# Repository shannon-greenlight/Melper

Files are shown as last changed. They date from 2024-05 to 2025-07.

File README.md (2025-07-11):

# The Melper
The Melper converts a Moog case into a powered Eurorack case.

It requires +12V as an input and generates -12V and +5V.
These 3 voltage rails supply 6 Eurorack power connectors.
Three LEDs monitor the supply rails.
It is targeted to Moog cases, but can be used in any case that has +12V.
The 12 volt wall wart that Moog supplies works well. 

This repo contains the schematic and layout files needed to create the Melper.
These files are for KiCAD Version: 8.0.8

The repo contains the BOM files that are used to buy the components.
These are found in the _BOM_ folder.
The BOM files for DigiKey and JLCPCB are provided in .csv format.
Other suppliers typically will accept these files with minor modifications.

The repo also contains the files needed for fabrication. These are found in the _fab_ folder.
These include the gerber files, which are provided both as a zip file and as the full unzipped folder structure.
Also included in the _fab_ folder are the files needed for pick-and-place.
The .xlsx file is the pick-and-place file. It is formatted for JLCPCB.
The raw position files are found in the _pos_ folder.

# Specs
The Melper derives -12V and +5V from the +12V supply.
- -12V
	- Voltage range: -11.75V thru -12.25V
	- Maximum current: 200mA
	- Line regulation: 15mV
	- Load regulation: 20mV
	- Ripple: 230mV
- +5V (see - [LM7805](https://www.ti.com/lit/ds/symlink/lm7800.pdf))
	- Voltage range: +4.8V thru +5.2V
	- Maximum current: 500mA @ 25C (more if heat-sink is used)
	- Line regulation: 3mV typ.
	- Load regulation: 10mV typ.
	- Ripple rejection: 80dB typ.

# Making Changes
The process of making changes usually starts with altering the schematic followed by other actions as required.
This requires a properly configured KiCAD installation. Download the KiCAD [repo](https://github.com/shannon-greenlight/KiCAD) and follow the instructions in the README to install.
When the system is configured follow the steps outlined below. Some steps are optional depending on what has changed.

These procedures have been optimized for use with Digi-Key and JLCPCB. They should be a good starting point for use with other vendors.

- Update schematic
- If any parts have changed, Update BOMs
	- From KiCAD Schematic Editor, run Tools->Generate Legacy Bill of Materials using bom2grouped_csv.xsl
		- bom2grouped_csv.xsl is found in the Greenface KiCAD repo.
		- Here is a sample command line: xsltproc -o "%O.csv" "C:\Users\shann\Dropbox\KiCAD\bom2grouped_csv.xsl" "%I"
		- This creates a .csv and an xsl file. The xml file is used in the next step.
	- Run _generate_boms.bat_
		- This creates 3 .csv files
			- BOM\Digi-Key\Melper_full.csv (all components)
			- BOM\Digi-Key\Melper_split.csv (just components not found in LCSC BOM)
			- BOM\LCSC\Melper_bom.csv (just components to be assembled by JLCPCB)
		- generate_boms.bat requires Python and the Greenface Python [libraries](https://github.com/shannon-greenlight/PYTHON_BOM) to be installed
			- Place the Greenface Python folder in a convienient place on your computer and set the variable %plugin_dir% to point to that folder location.
			- Python is invoked as 'py' in the batch file. This may need to be changed depending on your Python installation.
- Update layout if required
	- Plot the Gerber files
		- Set the output directory to _fab\gerber\\_
		- Make sure to Generate Drill Files
		- Create a zip archive of the Gerber files. (This is required by JLCPCB)
			- Use Windows Send To Compressed Folder. Rename the resulting file to melper_gerbers.zip
			- Alternatively, use zip_gerbers.bat
			- zip_gerbers.bat requires 7z.exe
			- Edit this file if 7z.exe is installed somewhere other than C:\Program Files\7-Zip
	- Create the pick-and-place files
		- From KiCAD PCB Editor, run File->Fabrication Outputs->Component Placement
		- Set the output directory to _fab\pos\\_
		- This creates the files used by the next step
		- Update melper_cpl.xlsx
			- melper_cpl.xlsx uses Excel Queries to convert pos\Melper-top-pos.csv into a format compatible with JLCPCB
			- Excel requires an absolute path to the source folder of the data. Edit the query to enter the path to your project.
			- *note: This process does not produce a perfect placement file due to differences in how KiCAD and JLCPCB orient components. However, JLCPCB is able to use the file without problems. So, even if the placement looks wrong when specifying the build, they will use the file and produce correct boards.
			- **note: There is probably a KiCAD plugin available that does a better job. The user is encouraged to try this route and report the results back.
- Upload to JLCPCB
	- JLCPCB requires the following files:
		- fab\melper_gerbers.zip
		- fab\melper_cpl.xlsx (only needed for assembly)
		- bom\LCSC\Melper_bom.csv (only needed for assembly)

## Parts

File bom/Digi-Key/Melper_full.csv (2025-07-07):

Reference | Quantity | Value | Digi-Key Part #
C1, C7, | 2 | 10uF | 445-173437-1-ND
C2, C4, | 2 | .1uF | 399-9877-1-ND
C3, | 1 | 330pF | 399-4231-ND
C8, | 1 | 1000uF | 1189-1545-1-ND
C9, C10, | 2 | 100uF | 1189-1300-ND
D1, | 1 | RED LED | 160-1035-ND
D2, | 1 | YELLOW LED | 160-1961-ND
D3, | 1 | GREEN LED | 732-5008-ND
D5, | 1 | 1N4001 | 1N4001RLGOSCT-ND
D6, | 1 | 1N5819 | 497-6610-1-ND
J1, J2, J3, J4, J5, J6, | 6 | Conn_02x08_Odd_Even | S9171-ND
J7, | 1 | Conn_01x02 | 900-0022232021-ND
L1, | 1 | 100uH | RLB0914-101KL-ND
L2, | 1 | 1.8uH | 495-76032-1-ND
R1, R3, | 2 | 10K | S10KQCT-ND
R2, | 1 | 4.7K | CF14JT4K70CT-ND
R4, | 1 | 953 | 13-MFR-25FRF52-953RCT-ND
R5, | 1 | 8.2K | MFR-25FBF52-8K2-ND
R6, | 1 | .33 | A138238CT-ND
TP1, | 1 | TestPoint | 36-5006-ND
U1, | 1 | LM7805_TO220 | 497-12404-ND
U2, | 1 | MC34063AD | 497-7412-5-ND

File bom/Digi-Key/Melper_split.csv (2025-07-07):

Reference | Quantity | Value | Digi-Key Part #
D1, | 1 | RED LED | 160-1035-ND
D2, | 1 | YELLOW LED | 160-1961-ND
D3, | 1 | GREEN LED | 732-5008-ND

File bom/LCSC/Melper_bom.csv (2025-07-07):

Designator | Comment | Footprint | JLCPCBPart#
C1, C7, | 10uF | Capacitor_THT:C_Disc_D5.1mm_W3.2mm_P5.00mm | C531341
C2, C4, | .1uF | Capacitor_THT:C_Disc_D4.3mm_W1.9mm_P5.00mm | C84772
C3, | 330pF | Capacitor_THT:C_Disc_D4.3mm_W1.9mm_P5.00mm | C2896045
C8, | 1000uF | Capacitor_THT:CP_Radial_D10.0mm_P5.00mm | C43909
C9, C10, | 100uF | Capacitor_THT:CP_Radial_D6.3mm_P2.50mm | C45075
D4, | Red SMT LED | LED_SMD:LED_0603_1608Metric_Pad1.05x0.95mm_HandSolder | C2286
D5, | 1N4001 | Diode_THT:D_DO-41_SOD81_P10.16mm_Horizontal | C895212
D6, | 1N5819 | Diode_THT:D_DO-41_SOD81_P7.62mm_Horizontal | C110032
D7, | Yellow SMT LED | LED_SMD:LED_0603_1608Metric_Pad1.05x0.95mm_HandSolder | C72038
D8, | Blue SMT LED | LED_SMD:LED_0603_1608Metric_Pad1.05x0.95mm_HandSolder | C2288
J1, J2, J3, J4, J5, J6, | Conn_02x08_Odd_Even | Connector_PinHeader_2.54mm:PinHeader_2x08_P2.54mm_Vertical | C305956
J7, | Conn_01x02 | Connector_PinHeader_2.54mm:PinHeader_1x02_P2.54mm_Vertical | C2905434
L1, | 100uH | Inductor_THT:L_Radial_D8.7mm_P5.00mm_Fastron_07HCP | C7343084
L2, | 1.8uH | Inductor_THT:L_Axial_L9.5mm_D4.0mm_P12.70mm_Horizontal_Fastron_SMCC | C17370623
L3, | 1.8uH | Inductor_SMD:L_Sunlord_SWPA4012S | C96867
R1, R3, | 10K | Resistor_THT:R_Axial_DIN0207_L6.3mm_D2.5mm_P10.16mm_Horizontal | C57436
R2, | 4.7K | Resistor_THT:R_Axial_DIN0207_L6.3mm_D2.5mm_P10.16mm_Horizontal | C176521
R4, | 953 | Resistor_THT:R_Axial_DIN0207_L6.3mm_D2.5mm_P10.16mm_Horizontal | C57435
R5, | 8.2K | Resistor_THT:R_Axial_DIN0207_L6.3mm_D2.5mm_P10.16mm_Horizontal | C172593
R6, | .33 | Resistor_THT:R_Axial_DIN0207_L6.3mm_D2.5mm_P10.16mm_Horizontal | C119970
TP1, | TestPoint | TestPoint:TestPoint_Keystone_5005-5009_Compact | C238124
U1, | LM7805_TO220 | Package_TO_SOT_THT:TO-220-3_Horizontal_TabDown | C111887
U2, | MC34063AD | Package_DIP:DIP-8_W7.62mm_LongPads | C5180

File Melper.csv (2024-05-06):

Reference | Quantity | Value | Footprint | Datasheet | Digi-Key Part
C1 C2 C5 C6 C7 | 5 | 10uF | Capacitor_THT:CP_Radial_D8.0mm_P5.00mm |  | 399-20957-1-ND
C3 C4 | 2 | .1uF | Capacitor_THT:C_Disc_D4.3mm_W1.9mm_P5.00mm |  | 399-9877-1-ND
D1 | 1 | RED LED | LED_THT:LED_D3.0mm |  | 160-1035-ND
D2 | 1 | YELLOW LED | LED_THT:LED_D3.0mm |  | 160-1961-ND
D3 | 1 | GREEN LED | LED_THT:LED_D3.0mm |  | 732-5008-ND
GR1 | 1 | small_logo | panel:small_face
GR2 | 1 | Logo_Open_Hardware_Small | Symbol:OSHW-Logo_5.7x6mm_SilkScreen
J1 J2 J3 J4 J5 J6 | 6 | Conn_02x08_Odd_Even | Connector_PinHeader_2.54mm:PinHeader_2x08_P2.54mm_Vertical |  | S9171-ND
J7 | 1 | Conn_01x02 | Connector_PinHeader_2.54mm:PinHeader_1x02_P2.54mm_Vertical |  | 900-0022232021-ND
L1 | 1 | 10uH | Inductor_THT:L_Radial_D8.7mm_P5.00mm_Fastron_07HCP |  | RLB0914-100KL-ND
R1 R3 | 2 | 10K | Resistor_THT:R_Axial_DIN0207_L6.3mm_D2.5mm_P10.16mm_Horizontal |  | S10KQCT-ND
R2 | 1 | 4.7K | Resistor_THT:R_Axial_DIN0207_L6.3mm_D2.5mm_P10.16mm_Horizontal |  | CF14JT4K70CT-ND
TP1 | 1 | TestPoint | TestPoint:TestPoint_Keystone_5005-5009_Compact |  | 36-5006-ND
TP2 TP3 TP4 | 3 | TestPoint | TestPoint:TestPoint_Pad_D2.0mm |  | 36-5006-ND
U1 | 1 | LM7805_TO220 | Package_TO_SOT_THT:TO-220-3_Horizontal_TabDown | https://www.onsemi.cn/PowerSolutions/document/MC7800-D.PDF | 497-12404-ND
U2 | 1 | VXO78012-1000 | Converter_DCDC:Converter_DCDC_Murata_OKI-78SR_Vertical | https://power.murata.com/data/power/oki-78sr.pdf | 102-4259-ND

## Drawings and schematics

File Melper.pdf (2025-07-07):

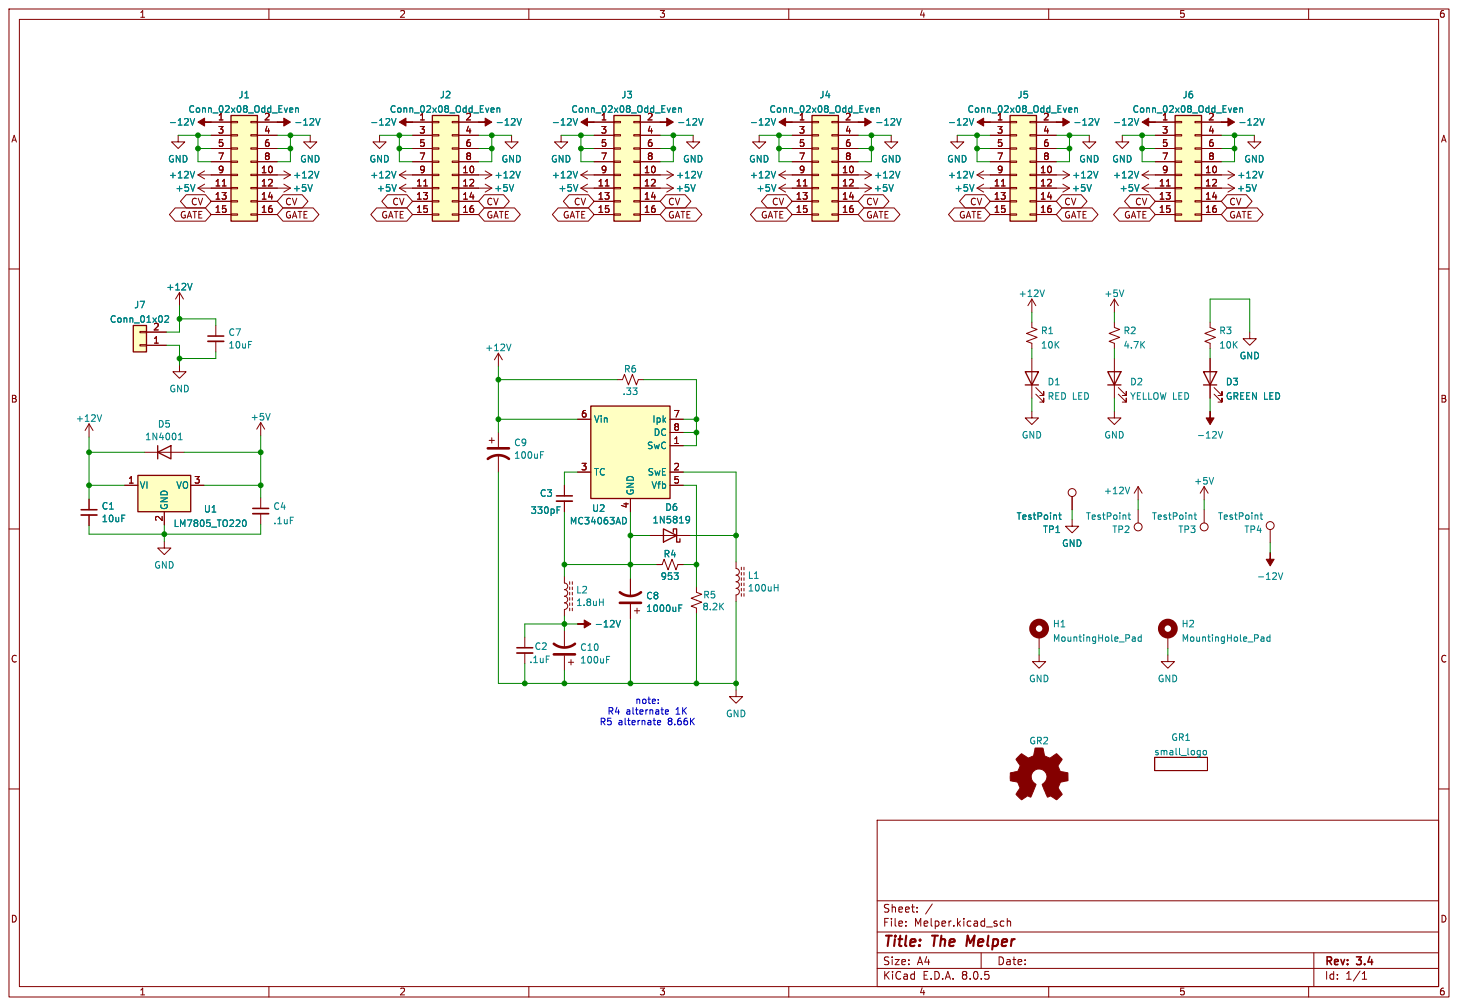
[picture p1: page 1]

D3 GREEN LED GND GND

Id: 1/1 Title: The Melper File: Melper.kicad_sch Sheet: /

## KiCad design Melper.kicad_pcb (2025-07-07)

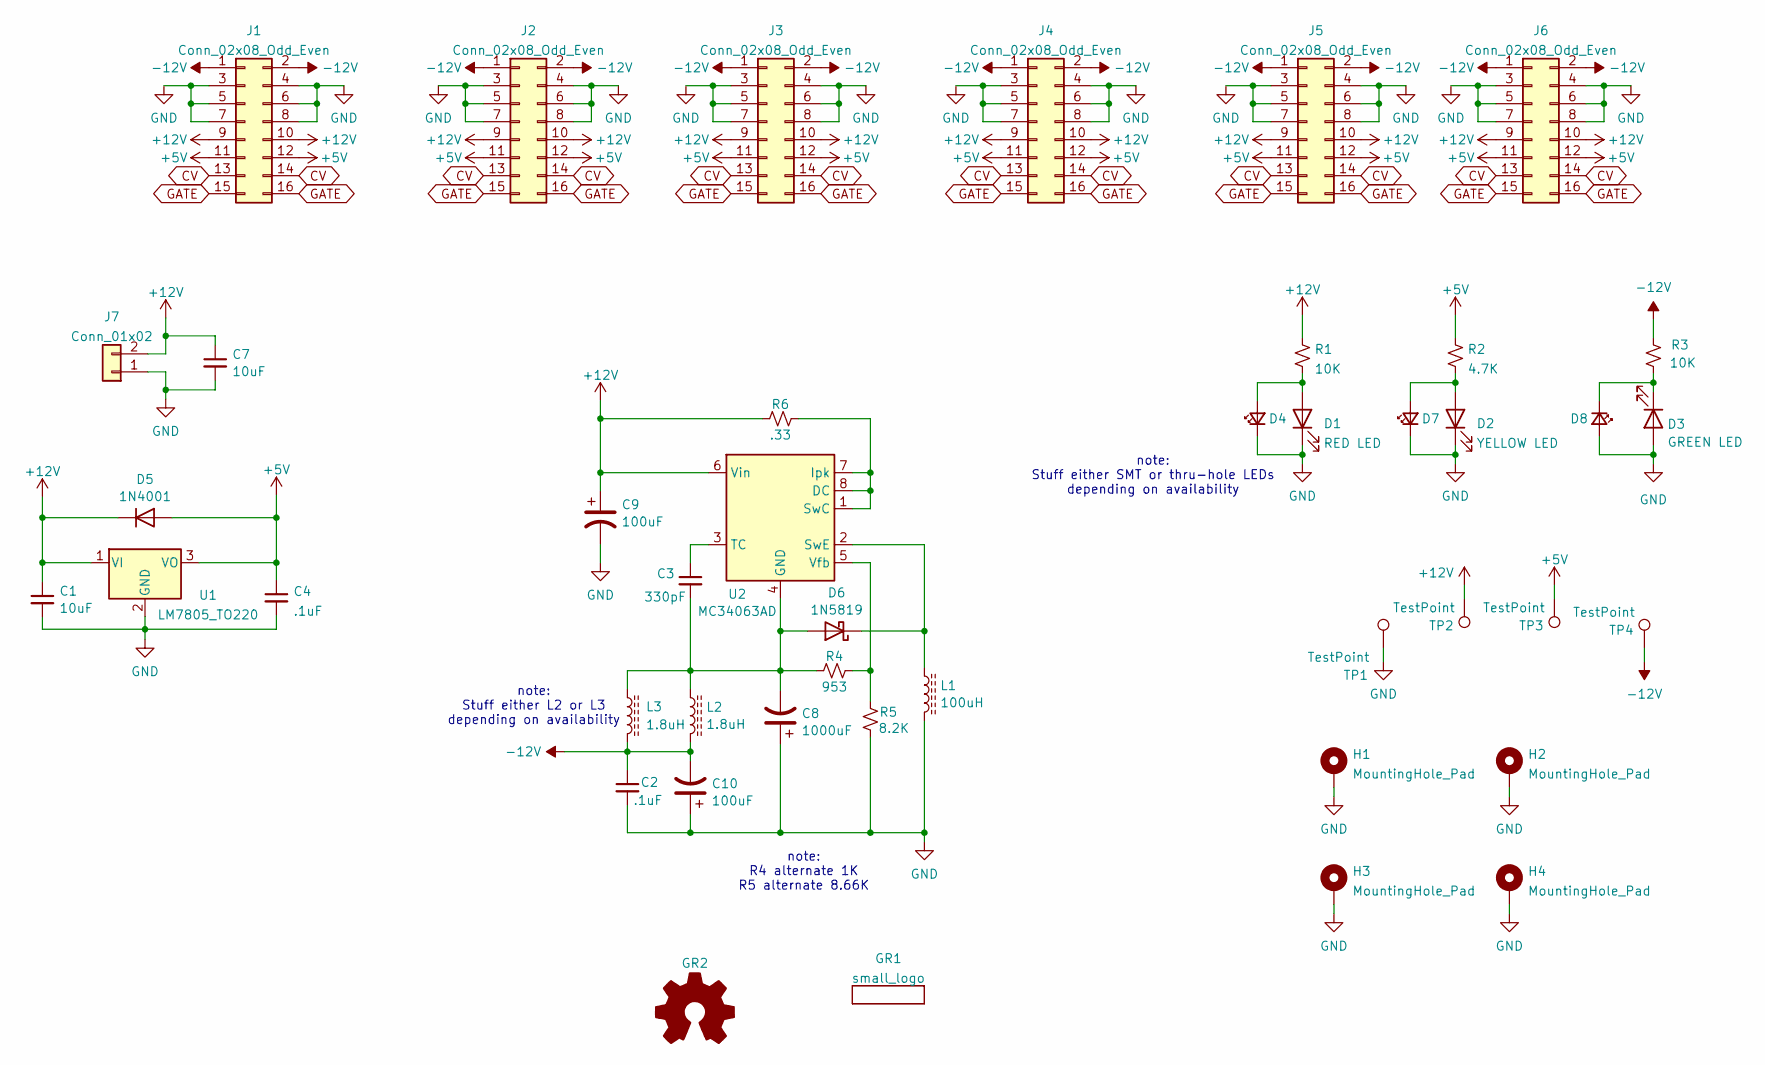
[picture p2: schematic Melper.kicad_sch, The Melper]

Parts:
C1, C7: 10uF; C_Disc_D5.1mm_W3.2mm_P5.00mm; Digi-Key Part 445-173437-1-ND
C2, C4: .1uF; C_Disc_D4.3mm_W1.9mm_P5.00mm; Digi-Key Part 399-9877-1-ND
C3: 330pF; C_Disc_D4.3mm_W1.9mm_P5.00mm; Digi-Key Part 399-4231-ND
C8: 1000uF; CP_Radial_D10.0mm_P5.00mm; Digi-Key Part 1189-1545-1-ND
C9, C10: 100uF; CP_Radial_D6.3mm_P2.50mm; Digi-Key Part 1189-1300-ND
D1: RED LED; LED_D3.0mm; Digi-Key Part 160-1035-ND
D2: YELLOW LED; LED_D3.0mm; Digi-Key Part 160-1961-ND
D3: GREEN LED; LED_D3.0mm; Digi-Key Part 732-5008-ND
D4: Red SMT LED; LED_0603_1608Metric_Pad1.05x0.95mm_HandSolder; LCSC Part # C2286
D5: 1N4001; D_DO-41_SOD81_P10.16mm_Horizontal; Digi-Key Part 1N4001RLGOSCT-ND
D6: 1N5819; D_DO-41_SOD81_P7.62mm_Horizontal; Digi-Key Part 497-6610-1-ND
D7: Yellow SMT LED; LED_0603_1608Metric_Pad1.05x0.95mm_HandSolder; LCSC Part # C72038
D8: Blue SMT LED; LED_0603_1608Metric_Pad1.05x0.95mm_HandSolder; LCSC Part # C2288
GR1: small_logo; small_face
GR2: Logo_Open_Hardware_Small; OSHW-Logo_5.7x6mm_SilkScreen
H1, H2, H3, H4: MountingHole_Pad; MountingHole_3.2mm_M3_DIN965_Pad
J1, J2, J3, J4, J5, J6: Conn_02x08_Odd_Even; PinHeader_2x08_P2.54mm_Vertical; Digi-Key Part S9171-ND
J7: Conn_01x02; PinHeader_1x02_P2.54mm_Vertical; Digi-Key Part 900-0022232021-ND
L1: 100uH; L_Radial_D8.7mm_P5.00mm_Fastron_07HCP; Digi-Key Part RLB0914-101KL-ND
L2: 1.8uH; L_Axial_L9.5mm_D4.0mm_P12.70mm_Horizontal_Fastron_SMCC; Digi-Key Part 495-76032-1-ND
L3: 1.8uH; L_Sunlord_SWPA4012S; LCSC Part # C96867
R1, R3: 10K; R_Axial_DIN0207_L6.3mm_D2.5mm_P10.16mm_Horizontal; Digi-Key Part S10KQCT-ND
R2: 4.7K; R_Axial_DIN0207_L6.3mm_D2.5mm_P10.16mm_Horizontal; Digi-Key Part CF14JT4K70CT-ND
R4: 953; R_Axial_DIN0207_L6.3mm_D2.5mm_P10.16mm_Horizontal; Digi-Key Part 13-MFR-25FRF52-953RCT-ND
R5: 8.2K; R_Axial_DIN0207_L6.3mm_D2.5mm_P10.16mm_Horizontal; Digi-Key Part MFR-25FBF52-8K2-ND
R6: .33; R_Axial_DIN0207_L6.3mm_D2.5mm_P10.16mm_Horizontal; Digi-Key Part A138238CT-ND
TP1: TestPoint; TestPoint_Keystone_5005-5009_Compact; Digi-Key Part 36-5006-ND
TP2, TP3, TP4: TestPoint; TestPoint_Pad_D2.0mm
U1: LM7805_TO220; TO-220-3_Horizontal_TabDown; Digi-Key Part 497-12404-ND
U2: MC34063AD; DIP-8_W7.62mm_LongPads; Digi-Key Part 497-7412-5-ND

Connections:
+5V: C4.1, D5.2 (A), J1.11, J1.12, J2.11, J2.12, J3.11, J3.12, J4.11, J4.12, J5.11, J5.12, J6.11, J6.12, R2.1, TP3.1, U1.3 (VO)
+12V: C1.1, C7.1, C9.1, D5.1 (K), J1.9, J1.10, J2.9, J2.10, J3.9, J3.10, J4.9, J4.10, J5.9, J5.10, J6.9, J6.10, J7.2, R1.1, R6.1, TP2.1, U1.1 (VI), U2.6 (Vin)
-12V: C2.1, C10.2, J1.1, J1.2, J2.1, J2.2, J3.1, J3.2, J4.1, J4.2, J5.1, J5.2, J6.1, J6.2, L2.2, L3.2, R3.2, TP4.1
CV: J1.13, J1.14, J2.13, J2.14, J3.13, J3.14, J4.13, J4.14, J5.13, J5.14, J6.13, J6.14
GATE: J1.15, J1.16, J2.15, J2.16, J3.15, J3.16, J4.15, J4.16, J5.15, J5.16, J6.15, J6.16
GND: C1.2, C2.2, C4.2, C7.2, C8.1, C9.2, C10.1, D1.1 (K), D2.1 (K), D3.2 (A), D4.1 (K), D7.1 (K), D8.2 (A), H1.1, H2.1, H3.1, H4.1, J1.3, J1.4, J1.5, J1.6, J1.7, J1.8, J2.3, J2.4, J2.5, J2.6, J2.7, J2.8, J3.3, J3.4, J3.5, J3.6, J3.7, J3.8, J4.3, J4.4, J4.5, J4.6, J4.7, J4.8, J5.3, J5.4, J5.5, J5.6, J5.7, J5.8, J6.3, J6.4, J6.5, J6.6, J6.7, J6.8, J7.1, L1.2, R5.1, TP1.1, U1.2 (GND)
unnamed: D1.2 (A), D4.2 (A), R1.2
unnamed: D2.2 (A), D7.2 (A), R2.2
unnamed: D3.1 (K), D8.1 (K), R3.1
unnamed: C3.2, C8.2, D6.2 (A), L2.1, L3.1, R4.1, U2.4 (GND)
unnamed: D6.1 (K), L1.1, U2.2 (SwE)
unnamed: R6.2, U2.1 (SwC), U2.7 (Ipk), U2.8 (DC)
unnamed: C3.1, U2.3 (TC)
unnamed: R4.2, R5.2, U2.5 (Vfb)

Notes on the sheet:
note: Stuff either L2 or L3 depending on availability
note: R4 alternate 1K R5 alternate 8.66K
note: Stuff either SMT or thru-hole LEDs depending on availability

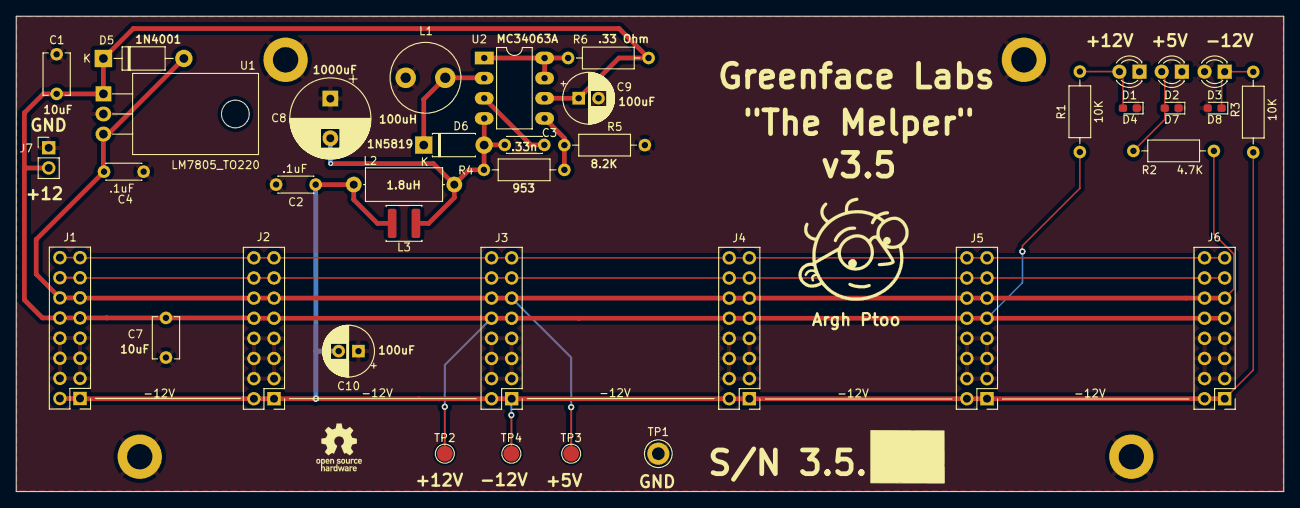
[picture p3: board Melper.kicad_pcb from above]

Board: 2 copper layers, 160.0 x 60.0 mm, 44 parts (0 on the bottom side), 14 nets.

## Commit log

2022-12-15 Init checkin of project
    [Melper-B_Cu.gbr, Melper-B_Mask.gbr, Melper-B_Paste.gbr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]
2022-12-15 Update Melper.kicad_sch
    Changes LED resistors.
    [Melper.kicad_sch]
2022-12-15 Adds BOM
    [Melper.csv, Melper_full.csv]
2023-10-19 Version 2.1
    [Melper-B_Cu.gbr, Melper-B_Mask.gbr, Melper-B_Paste.gbr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]
2023-10-20 Version 3
    Adds 6th power connector.
    [Melper-B_Cu.gbr, Melper-B_Mask.gbr, Melper-B_Paste.gbr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]
2024-05-06 Rev 3.2
    [Melper-B_Cu.gbr, Melper-B_Mask.gbr, Melper-B_Paste.gbr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]
2025-07-07 Revision 3.5
    Changes negative regulator.
    Adds support for JLC build.
    [Melper-B_Cu.gbr, Melper-B_Mask.gbr, Melper-B_Paste.gbr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]
2025-07-11 Update README.md
    Adds voltage range spec
